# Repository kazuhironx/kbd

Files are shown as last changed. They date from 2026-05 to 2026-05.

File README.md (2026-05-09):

# kbd

自作キーボード設計用のリポジトリです。

最初の対象は、Lily58 系より少しだけ記号に強い左右分割キーボードです。HHKB US 配列に慣れた Emacs 利用を前提に、column staggered の分割配列と、手持ちの SA Symbiosis / ortho 系キーキャップを活かす設計にします。

## 方針

- 左右分割、現行 Ergogen 案は片手 31 キー、合計 62 キー
- 有線 USB 接続
- 左右間接続は TRRS または JST を比較し、初期生成物は TRRS
- Keebio RP2040 Pro Micro 16MB を第一候補にした Pro Micro 互換フットプリント
- MX 5-pin direct solder
- plateless、1.6mm PCB、4mm spacer、1.6mm FR4 bottom plate
- LED、OLED、ロータリーエンコーダ、無線、電池は v1 では入れない
- `Space` は 2u キーキャップの優先候補
- `Ctrl` と `Enter` は 1u / 1.5u の差し替え候補として扱い、キーキャップ高さ確認後に確定する
- `[` と `]` は G/H の内側人差し指キーとして Base layer に置く
- 親指クラスタは片手 5 キーを残すが、常用は 3 キーまでに絞る
- 左親指 `Ctrl` と右親指 `Space` は 2u の対称配置にする
- `-` / `+` は T/Y の内側に置き、レイヤなしで押せる記号枠として扱う
- Ergogen の `ergogen/config.yaml` を物理配置とPCB外形の一次情報にする

## ディレクトリ

- `docs/`: レイアウト、キーキャップ、ピン割り当ての設計メモ
- `ergogen/`: 物理レイアウト、PCB外形、生成用設定
- `hardware/split60_ortho/`: KiCad プロジェクト
- `firmware/qmk/kazuhironx_split60_ortho/`: QMK キーボード定義の雛形

## Ergogen

```sh
npm install
npm run ergogen
```

確認用SVGは `docs/generated/` に、KiCadで開く生成PCBは `hardware/split60_ortho/generated/` に置きます。

## 次の作業

1. `docs/generated/split60-preview.svg` で親指クラスタと内側記号キーの位置を確認する。
2. KiCad 10.0.1 で `hardware/split60_ortho/generated/split60_left.kicad_pcb` を開き、外形、MX、ダイオード、MCU、TRRS位置を確認する。
3. Keebio RP2040 Pro Micro 16MB の実寸とUSB-C逃げに合わせてMCU位置を詰める。
4. 回路図、配線、DRC、Gerber出力へ進む。

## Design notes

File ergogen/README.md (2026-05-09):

# Ergogen source

This directory is the source of truth for the physical layout and generated PCB assets.

## Generate

```bash
npm install
npm run ergogen
```

Outputs are written to `ergogen/output/` and ignored by Git. Copy checked/generated KiCad artifacts into `hardware/split60_ortho/` only after review.

## Design intent

- MX 5-pin direct solder
- SA Symbiosis keycaps
- Plateless
- 1.6mm main PCB
- 4mm spacer
- 1.6mm FR4 bottom plate
- Keebio RP2040 Pro Micro 16MB as the first MCU target
- Split wired QMK

The thumb cluster is intentionally parameterized in `config.yaml` so the `Alt`, `Ctrl(2u)`, `Space(2u)`, and `Fn` positions can be tuned by feel.

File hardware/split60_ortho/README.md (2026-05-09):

# split60_ortho hardware

KiCad 用の作業ディレクトリです。

v1 の回路設計対象:

- 左右別基板
- Keebio RP2040 Pro Micro 16MB 第一候補の Pro Micro 互換フットプリント
- TRRS ジャック
- RESET スイッチ
- 片手31キー分の MX 5-pin direct solder
- 各キーのダイオード
- LED / OLED / encoder / wireless はなし

`generated/split60_left.kicad_pcb` は Ergogen から生成した初期PCBです。KiCad 10.0.1で開き、MCU位置、USB-C逃げ、ねじ穴、底板逃げを確認してから本配線へ進みます。

回路図作成後に ERC を実行し、QMK の matrix と一致していることを確認します。

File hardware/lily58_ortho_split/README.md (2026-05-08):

# lily58_ortho_split hardware

KiCad 用の作業ディレクトリです。

v1 の回路設計対象:

- 左右別基板
- Pro Micro 互換フットプリント
- TRRS ジャック
- RESET スイッチ
- 58 キー分の MX ホットスワップソケット
- 各キーのダイオード
- LED / OLED / encoder / wireless はなし

回路図作成後に ERC を実行し、QMK の matrix と一致していることを確認します。

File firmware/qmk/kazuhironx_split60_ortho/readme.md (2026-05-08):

# kazuhironx_split60_ortho

QMK keyboard definition draft for the 60-key split keyboard.

This is a scaffold. Pin assignments and diode direction must be confirmed against the KiCad schematic before building firmware.

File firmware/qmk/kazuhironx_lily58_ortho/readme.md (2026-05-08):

# kazuhironx_lily58_ortho

QMK keyboard definition draft for the 58-key split keyboard.

This is a scaffold. Pin assignments and diode direction must be confirmed against the KiCad schematic before building firmware.

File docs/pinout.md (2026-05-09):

# ピン割り当てメモ

## 前提

- MCU: Keebio RP2040 Pro Micro 16MB 第一候補
- footprint: Pro Micro 互換、裏面実装、直ハンダ前提
- 左右間接続: TRRS または JST を比較、初期生成物は TRRS
- スイッチ: MX 5-pin direct solder
- ダイオード: 各スイッチに 1 個
- キー数: 現行 Ergogen 案は左右 31 キーずつ、合計 62 キー

## Matrix draft

片手 31 キーを 5 行 x 6 列相当の matrix に収めます。T/Y 内側の `-` / `+` は `matrix_symbol_top`、G/H 内側の `[` / `]` は `matrix_symbol_home` として扱います。親指クラスタは `thumb_alt`, `thumb_lower`, `thumb_ctrl`, `thumb_fn` を独立点名にしています。

```text
row0: k00 k01 k02 k03 k04 k05
row1: k10 k11 k12 k13 k14 k15
row2: k20 k21 k22 k23 k24 k25
row3: k30 k31 k32 k33 k34 k35
row4: k40 k41 k42 k43 k44 k45
```

## RP2040 pin draft

この表は論理net名です。KiCad 回路図作成時に、Keebio RP2040 Pro Micro 16MB の実物ピンと配線しやすさを見てGPIOへ割り当てます。

```text
Rows: R0, R1, R2, R3, R4
Cols: C0, C1, C2, C3, C4, C5
Split data: TBD
Reset: RESET pin + tactile switch to GND
```

## TRRS draft

TRRS の割り当ても仮置きです。左右で必ず同一の割り当てにします。

```text
Tip:    VCC
Ring1:  Serial
Ring2:  GND
Sleeve: Reserved / no connect
```

## 確認事項

- TRRS の VCC/GND/Serial 割り当てはジャックの実フットプリントで確認する。
- Pro Micro 互換ボードによりラベルとRP2040 GPIO名が異なるため、QMK 側の指定名と照合する。
- `DIODE_DIRECTION` は回路図のダイオード向き確定後に固定する。

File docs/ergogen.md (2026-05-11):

# Ergogen設計メモ

## 方針

Ergogenを物理レイアウトの一次情報にする。KiCadでは生成されたPCBを確認し、回路図・配線・DRC・Gerber出力へ進める。

## 生成対象

- `split60_left`: 左手側PCBの初期生成物
- `board`: PCB外形
- `preview`: キー位置確認用
- `bottom_plate`: FR4 bottom plate用外形

`npm run ergogen` は SVG も生成します。確認用に以下をリポジトリへコピーしています。

- `docs/generated/split60-preview.svg`
- `docs/generated/split60-board.svg`
- `docs/generated/split60-bottom-plate.svg`
- `hardware/split60_ortho/generated/split60_left.kicad_pcb`

## 調整ポイント

- `thumb.alt`, `thumb.lower`, `thumb.main`, `thumb.fn` の `shift`, `rotate`, `width`
- `matrix.*.stagger`
  - 現行は `ring.stagger: 4`, `middle.stagger: 8`, `index.stagger: 4`, `inner.stagger: 0`。QからW/Eへ上げ、R/Tへ向けて下げてTをQと同じ高さに戻す。
- `outlines._raw` の外形点
- mounting holes の位置

## 注意

- `Ctrl(2u)` と `Space(2u)` は左右対称運用を前提にする。
- `Alt` は1.5u候補。`Ctrl+Alt+...` を親指で押しやすい位置を優先する。
- ねじ穴候補は `_mounting_holes` に残すが、レイアウト確認時のノイズを避けるため `board` からは一旦 subtract していない。KiCad配線段階で最終穴径と位置を戻す。
- Ergogen標準footprintで不足が出た場合は、カスタムfootprint化する。Keebio RP2040 Pro Micro 16MBの最終フットプリントは実寸確認後に詰める。
- QMK雛形は前段のビルド確認用で、まだRP2040/62キーの最終matrixには合わせていない。Ergogen配置確認後に更新する。
- 公式Ergogenのpoint previewでは左右両側が表示されるため、`mirror.distance` は中央干渉が出ないよう広めの `96` にしている。左手PCB生成物はmirror点を除外している。

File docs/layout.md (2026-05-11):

# レイアウト案

## 概要

Lily58 系より記号に強い split ergonomic 構成です。現行 Ergogen 案は左右それぞれ 31 キー、合計 62 キーです。メイン部は基本 4 行 x 6 列に、T/Y の内側へ `-` / `+`、G/H の内側へ `[` / `]` を足します。親指クラスタは片手 5 キーにして、常用は押しやすい 3 キーに絞ります。

手持ちの ortho 系 1u キーキャップを中心に使い、少数ある 2u と 1.5u は親指クラスタと外側修飾キーに割り当てます。

## Base layer

図面ラフ:

layout draft

Ergogen 生成プレビュー:

ergogen preview

```text
Left                                      Right

Esc   1   2   3   4   5                  6   7   8   9   0   `
Tab   Q   W   E   R   T   -          +   Y   U   I   O   P   Backspace
Ctrl  A   S   D   F   G   [          ]   H   J   K   L   ;   Enter
Shift Z   X   C   V   B                  N   M   ,   .   /   \|

          Alt Lower Ctrl(2u)           Space(2u) Raise Enter
                 Fn                    Fn
```

## キーキャップ活用

- 1u: 英数字、記号、基本的な修飾キーに使う。
- 2u: 左親指 `Ctrl` と右親指 `Space` に使う。左右の親指主キーを同じ大きさ・角度にして、見た目と押し心地の対称性を優先する。
- 1.5u: 左外側 `Ctrl` と右外側 `Enter` の候補にする。どちらも外側へ突き出す配置にして、左右の列間隔を対称にしやすくする。
- 親指クラスタ下段は `Fn` のみ残す。`-` / `+` は T/Y の内側へ移し、人差し指で押せる記号キーにする。

## レイヤ方針

- `[` と `]` は Base layer の内側人差し指キーに置く。
- Lower は `{}`, `()`, その他記号、カーソル移動を中心にする。
- Raise は function keys、追加記号、必要なら media / mouse keys を置く。
- Emacs 用に `Ctrl` は左ホーム列と左親指の両方に置ける構成にする。
- `Enter` は右外側にも残しつつ、右親指にも置く。親指 Enter に慣れる余地を作る。
- `Alt` は `Ctrl+Alt+...` を押しやすいよう、左親指の常用3キー内に置く。左親指で `Ctrl(2u)` と `Alt` を押し分けられることを優先する。
- `-` と `+` は T/Y の内側に置く。B/N 内側より上段寄りで、親指クラスタと干渉しにくい位置を優先する。

## PCB 上の注意

- 2u 候補位置はスタビライザー穴を検討する。
- 1.5u 候補位置はキーキャップ干渉と隣接キー間隔を確認する。
- メイン部は 1u 前提で、左 `Ctrl` は左外側へ、右 `Enter` は右外側へ突き出す。内側に食わせない。
- 親指クラスタは Corne の「3 thumb keys」を参考に、常用3キーを扇形にまとめる。追加1キーは `Fn` として主動線から少し外す。
- 左親指 `Ctrl` と右親指 `Space` はどちらも 2u とし、鏡映対称の位置・角度にする。他の親指キーも同じ扇形に沿って回転させる。

## 拡張候補

60 キーへ戻すなら、左右の `Fn` を削るのが最も素直です。現行案は `-` / `+` と `[` / `]` を Base layer に残すため、62 キーを許容しています。

物理キーとしてさらに増やすなら、B/N の内側へ追加記号を置く案があります。ただし B/N の内側は親指クラスタと近く、下段の人差し指移動も増えるため優先度を下げます。
- column stagger は控えめな段差にして、HHKB から移行しても指が迷いにくい範囲にする。
- `E/D/C` と `I/K/,` に近い middle column をピークにして、QからW/Eへ上げ、R/Tへ向けて下げる。`T/G/B` と `Y/H/N` の inner column はQ列と同じ高さへ戻し、日本語入力、Emacs、tmux で内側人差し指を酷使しやすい前提で、上段内側キーを無理に高くしない。
- 親指クラスタは青箱メモに合わせる。外側に1u水平、次に2u水平、B/Nの右下に1u斜め、その内側に2u斜めを置く。mounting holeはレイアウト確認の邪魔になるため、現段階のpreview外形からは外す。
- 左右別基板なので、シルクと部品向きは読みやすさを優先する。

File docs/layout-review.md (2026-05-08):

# レイアウト確認メモ

## 確認したいポイント

- `Space` は右親指の 2u 候補です。
- `Ctrl` と `Enter` は 1.5u 候補ですが、手持ちキーキャップの高さ確認後に 1u へ戻せる扱いにしています。
- `[` と `]` は Base layer の G/H 内側に置き、人差し指で押す記号キーにします。
- 左 `Ctrl` は左外側へ、右 `Enter` は右外側へ突き出す対称配置にします。
- 親指クラスタは Corne 風に斜めへ流し、キー自体も回転させます。常用は片手 3 キーまでにします。
- 左親指 `Ctrl` と右親指 `Space` はどちらも 2u にして、鏡映対称の位置・角度にします。
- 左手 `Alt` は `Ctrl+Alt+...` 用に、左親指の常用キーとして押しやすい位置に残します。
- `-` と `+` は T/Y の内側に置き、60キーのまま維持します。
- 親指クラスタ下段は `Fn` だけ残します。

## 物理配置ラフ

```text
Left half                               Right half

Esc   1   2   3   4   5                 6   7   8   9   0   `
 Tab  Q   W   E   R   T   -         +   Y   U   I   O   P   Bspc
 Ctrl A   S   D   F   G   [         ]   H   J   K   L   ;   Enter
Shift Z   X   C   V   B                 N   M   ,   .   /   \|

             Alt Lower Ctrl(2u)        Space(2u) Raise Enter
                    Fn                 Fn
```

## 差し替え候補

`Ctrl` の高さが合わない場合:

- 左ホーム列の `Ctrl` を 1u に戻す。
- 1.5u の `Ctrl` は外側へ突き出すので、A とは重ねない。
- Emacs 用の親指 `Ctrl` は 2u の主キーとして維持する。

`Enter` の高さが合わない場合:

- 右ホーム列の `Enter` を 1u に戻す。
- 1.5u の `Enter` は右親指クラスタ側に回す。
- 右外側の `Backspace` を 1.5u 候補にする。

`Space` の 2u が干渉する場合:

- 右親指の `Space` を 1u に戻す。
- 2u はケースとPCBの実測後に再配置する。

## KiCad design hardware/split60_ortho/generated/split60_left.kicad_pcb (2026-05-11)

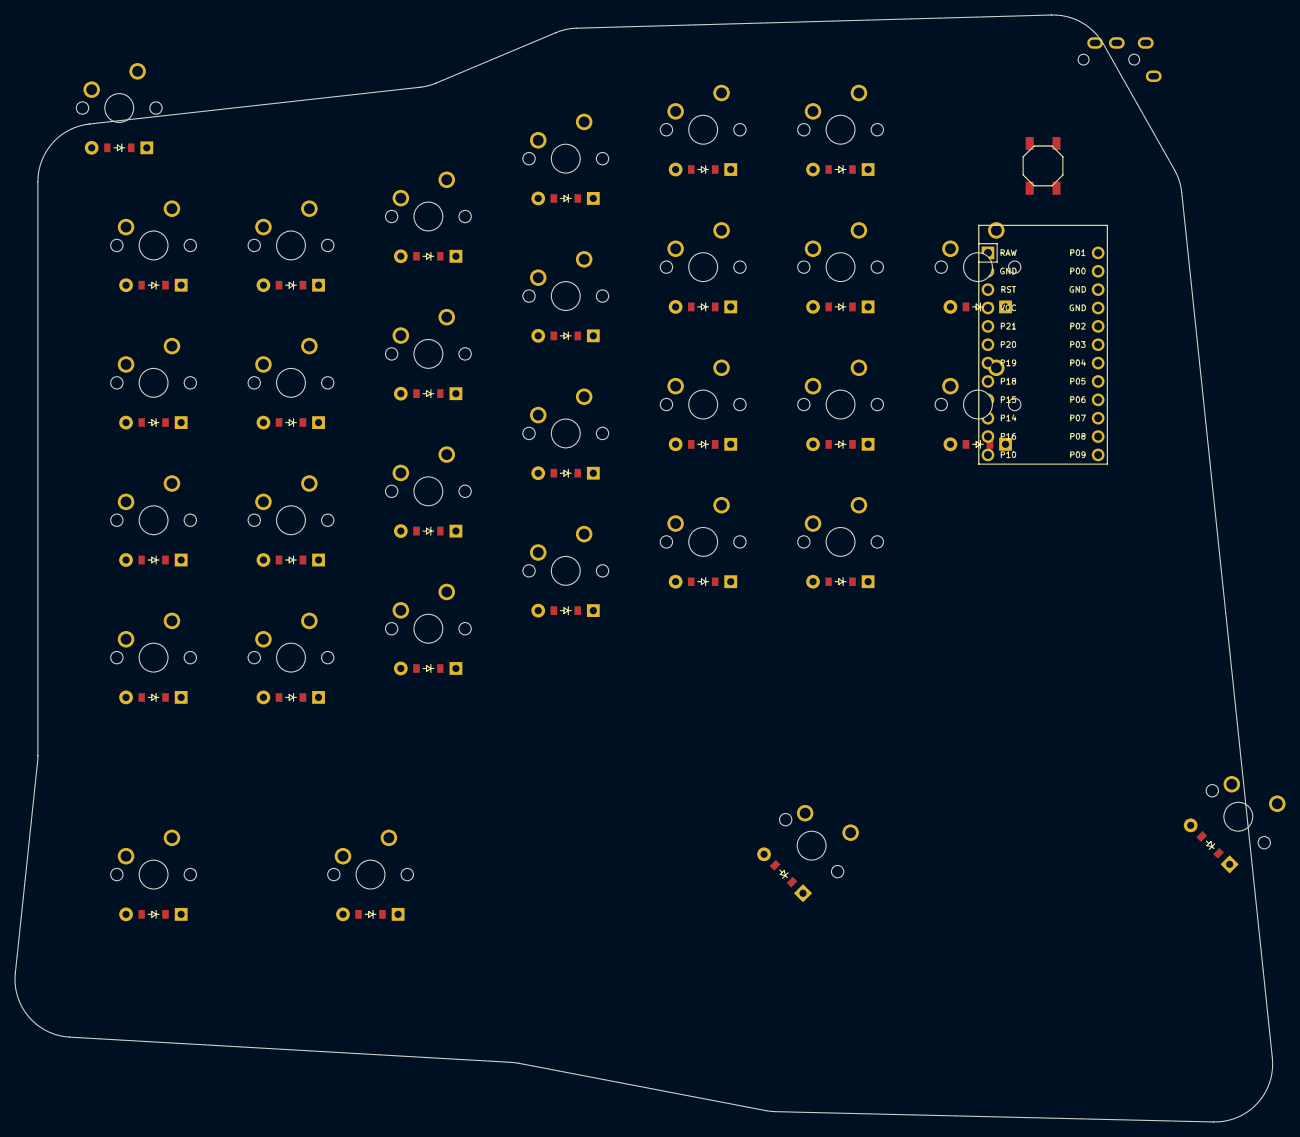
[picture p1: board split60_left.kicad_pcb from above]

Board: 2 copper layers, 173.9 x 153.1 mm, 65 parts (0 on the bottom side), 46 nets, no tracks yet.

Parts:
B1: SW_TACT_ALPS_SKQGABE010
D1, D2, D3, D4, D5, D6, D7, D8, D9, D10, D11, D12, D13, D14, D15, D16, D17, D18, D19, D20, D21, D22, D23, D24, D25, D26, D27, D28, D29, D30, D31: ComboDiode
MCU1: ProMicro
S1, S2, S3, S4, S5, S6, S7, S8, S9, S10, S11, S12, S13, S14, S15, S16, S17, S18, S19, S20, S21, S22, S23, S24, S25, S26, S27, S28, S29, S30, S31: MX
TRRS1: TRRS-PJ-320A-dual

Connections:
C0: S1.1, S2.1, S3.1, S4.1, S5.1, S28.1
C1: S6.1, S7.1, S8.1, S9.1, S29.1
C2: S10.1, S11.1, S12.1, S13.1, S30.1
C3: S14.1, S15.1, S16.1, S17.1, S31.1
C4: S18.1, S19.1, S20.1, S21.1, S26.1, S27.1
C5: S22.1, S23.1, S24.1, S25.1
GND: B1.2, MCU1.2, MCU1.15, MCU1.16, TRRS1.2, TRRS1.4
P2: MCU1.17, TRRS1.3
R0: D4.1, D9.1, D13.1, D17.1, D21.1, D25.1
R1: D3.1, D8.1, D12.1, D16.1, D20.1, D24.1, D27.1
R2: D2.1, D7.1, D11.1, D15.1, D19.1, D23.1, D26.1
R3: D1.1, D6.1, D10.1, D14.1, D18.1, D22.1
R4: D28.1, D29.1, D30.1, D31.1
RST: B1.1, MCU1.3
VCC: MCU1.4, TRRS1.1
matrix_index_bottom: D18.2, S18.2
matrix_index_home: D19.2, S19.2
matrix_index_number: D21.2, S21.2
matrix_index_top: D20.2, S20.2
matrix_inner_bottom: D22.2, S22.2
matrix_inner_home: D23.2, S23.2
matrix_inner_number: D25.2, S25.2
matrix_inner_top: D24.2, S24.2
matrix_middle_bottom: D14.2, S14.2
matrix_middle_home: D15.2, S15.2
matrix_middle_number: D17.2, S17.2
matrix_middle_top: D16.2, S16.2
matrix_outer_bottom: D1.2, S1.2
matrix_outer_home: D2.2, S2.2
matrix_outer_mod: D5.2, S5.2
matrix_outer_number: D4.2, S4.2
matrix_outer_top: D3.2, S3.2
matrix_pinky_bottom: D6.2, S6.2
matrix_pinky_home: D7.2, S7.2
matrix_pinky_number: D9.2, S9.2
matrix_pinky_top: D8.2, S8.2
matrix_ring_bottom: D10.2, S10.2
matrix_ring_home: D11.2, S11.2
matrix_ring_number: D13.2, S13.2
matrix_ring_top: D12.2, S12.2
matrix_symbol_home: D26.2, S26.2
matrix_symbol_top: D27.2, S27.2
thumb_alt: D28.2, S28.2
thumb_ctrl: D30.2, S30.2
thumb_fn: D31.2, S31.2
thumb_lower: D29.2, S29.2

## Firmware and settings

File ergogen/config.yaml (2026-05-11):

meta:
  engine: 4.1.0
  name: split60_ortho
  version: 0.1.0
  author: kazuhironx

units:
  kx: 19
  ky: 19
  cap: 18
  pad: 3
  board_margin: 8
  screw: 2.2
  screw_radius: 1.1
  spacer: 4

points:
  rotate: 0
  mirror:
    ref: matrix_inner_home
    distance: 96
  zones:
    matrix:
      anchor:
        shift: [0, 0]
      key:
        padding: ky
        spread: kx
        tags:
          - key
      columns:
        outer:
          key:
            column_net: C0
          rows:
            mod:
              width: 1.5
              shift: [-4.75, 0]
        pinky:
          key:
            column_net: C1
        ring:
          key:
            stagger: 4
            column_net: C2
        middle:
          key:
            stagger: 8
            column_net: C3
        index:
          key:
            stagger: 4
            column_net: C4
        inner:
          key:
            stagger: 0
            column_net: C5
        symbol:
          key:
            stagger: 0
            column_net: C4
            shift: [0, 0]
          rows:
            number:
              skip: true
            bottom:
              skip: true
      rows:
        bottom:
          row_net: R3
        home:
          row_net: R2
        top:
          row_net: R1
        number:
          row_net: R0
    thumb:
      anchor:
        ref: matrix_outer_bottom
        shift: [0, -30]
      key:
        padding: ky
        spread: kx
        tags:
          - key
          - thumb
      columns:
        alt:
          key:
            name: thumb_alt
            column_net: C0
            row_net: R4
            width: 2
            rotate: 0
            shift: [30, 0]
        lower:
          key:
            name: thumb_lower
            column_net: C1
            row_net: R4
            rotate: -45
            shift: [72, 4]
        main:
          key:
            name: thumb_ctrl
            column_net: C2
            row_net: R4
            width: 2
            rotate: -45
            shift: [112, 8]
        fn:
          key:
            name: thumb_fn
            column_net: C3
            row_net: R4
            rotate: 0
            shift: [-57, 0]
      rows:
        cluster:

outlines:
  _keys:
    - what: rectangle
      where:
        - - key
          - "-/^mirror_/"
      size: [cap, cap]
  _switch_cutouts:
    - what: rectangle
      where:
        - - key
          - "-/^mirror_/"
      size: [14, 14]
  _wide_keys:
    - what: rectangle
      where:
        - ref: thumb_alt
        - ref: thumb_ctrl
      size: [37, 18]
  _mounting_holes:
    - what: circle
      radius: screw_radius
      where:
        - ref: matrix_outer_number
          shift: [-6, 8]
        - ref: matrix_inner_number
          shift: [42, 8]
        - ref: matrix_outer_bottom
          shift: [-6, -10]
        - ref: thumb_alt
          shift: [-14, -16]
        - ref: thumb_ctrl
          shift: [32, -18]
  _raw:
    - what: polygon
      operation: stack
      points:
        - ref: matrix_outer_number
          shift: [-board_margin - 8, board_margin + 8]
        - ref: matrix_ring_number
          shift: [0, board_margin + 10]
        - ref: matrix_middle_number
          shift: [0, board_margin + 10]
        - ref: matrix_inner_number
          shift: [board_margin + 26, board_margin + 8]
        - ref: matrix_symbol_top
          shift: [board_margin + 20, board_margin + 4]
        - ref: thumb_ctrl
          shift: [board_margin + 26, -board_margin - 18]
        - ref: thumb_lower
          shift: [board_margin + 14, -board_margin - 22]
        - ref: thumb_alt
          shift: [board_margin + 12, -board_margin - 18]
        - ref: thumb_fn
          shift: [-board_margin - 12, -board_margin - 14]
        - ref: matrix_outer_bottom
          shift: [-board_margin - 8, -board_margin - 6]
      fillet: 8
  board:
    - what: outline
      name: _raw
  preview:
    - what: outline
      name: board
    - what: outline
      name: _keys
      operation: subtract
    - what: outline
      name: _wide_keys
      operation: subtract
  bottom_plate:
    - what: outline
      name: board
    - what: outline
      name: _switch_cutouts
      operation: subtract
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

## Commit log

2026-05-08 Initial keyboard project scaffold
    [lily58_ortho_split.kicad_sch]
2026-05-08 Revise layout to split 60
    [split60_ortho.kicad_sch]
2026-05-08 Update QMK scaffold for current keyboard json
2026-05-09 Add Ergogen split keyboard layout
    [split60_left.kicad_pcb]
2026-05-09 Lower inner index columns
    [split60_left.kicad_pcb]
2026-05-09 Refine column stagger and thumb outline
    [split60_left.kicad_pcb]
2026-05-10 Rework QWERT stagger and thumb cluster
    [split60_left.kicad_pcb]
2026-05-11 Adjust thumb cluster preview layout
    [split60_left.kicad_pcb]
